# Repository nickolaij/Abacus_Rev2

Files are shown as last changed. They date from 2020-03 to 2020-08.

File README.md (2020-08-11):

# Abacus Mechanical Keyboard

A 45% mechanical keyboard that includes an encoder volume/scroll wheel and RGB lighting. 

This keyboard is powered by QMK, visit the [QMK Repository](https://github.com/qmk/qmk_firmware/) to see all the amazing keyboards supported by them.

AbacusBack
AbacusFront

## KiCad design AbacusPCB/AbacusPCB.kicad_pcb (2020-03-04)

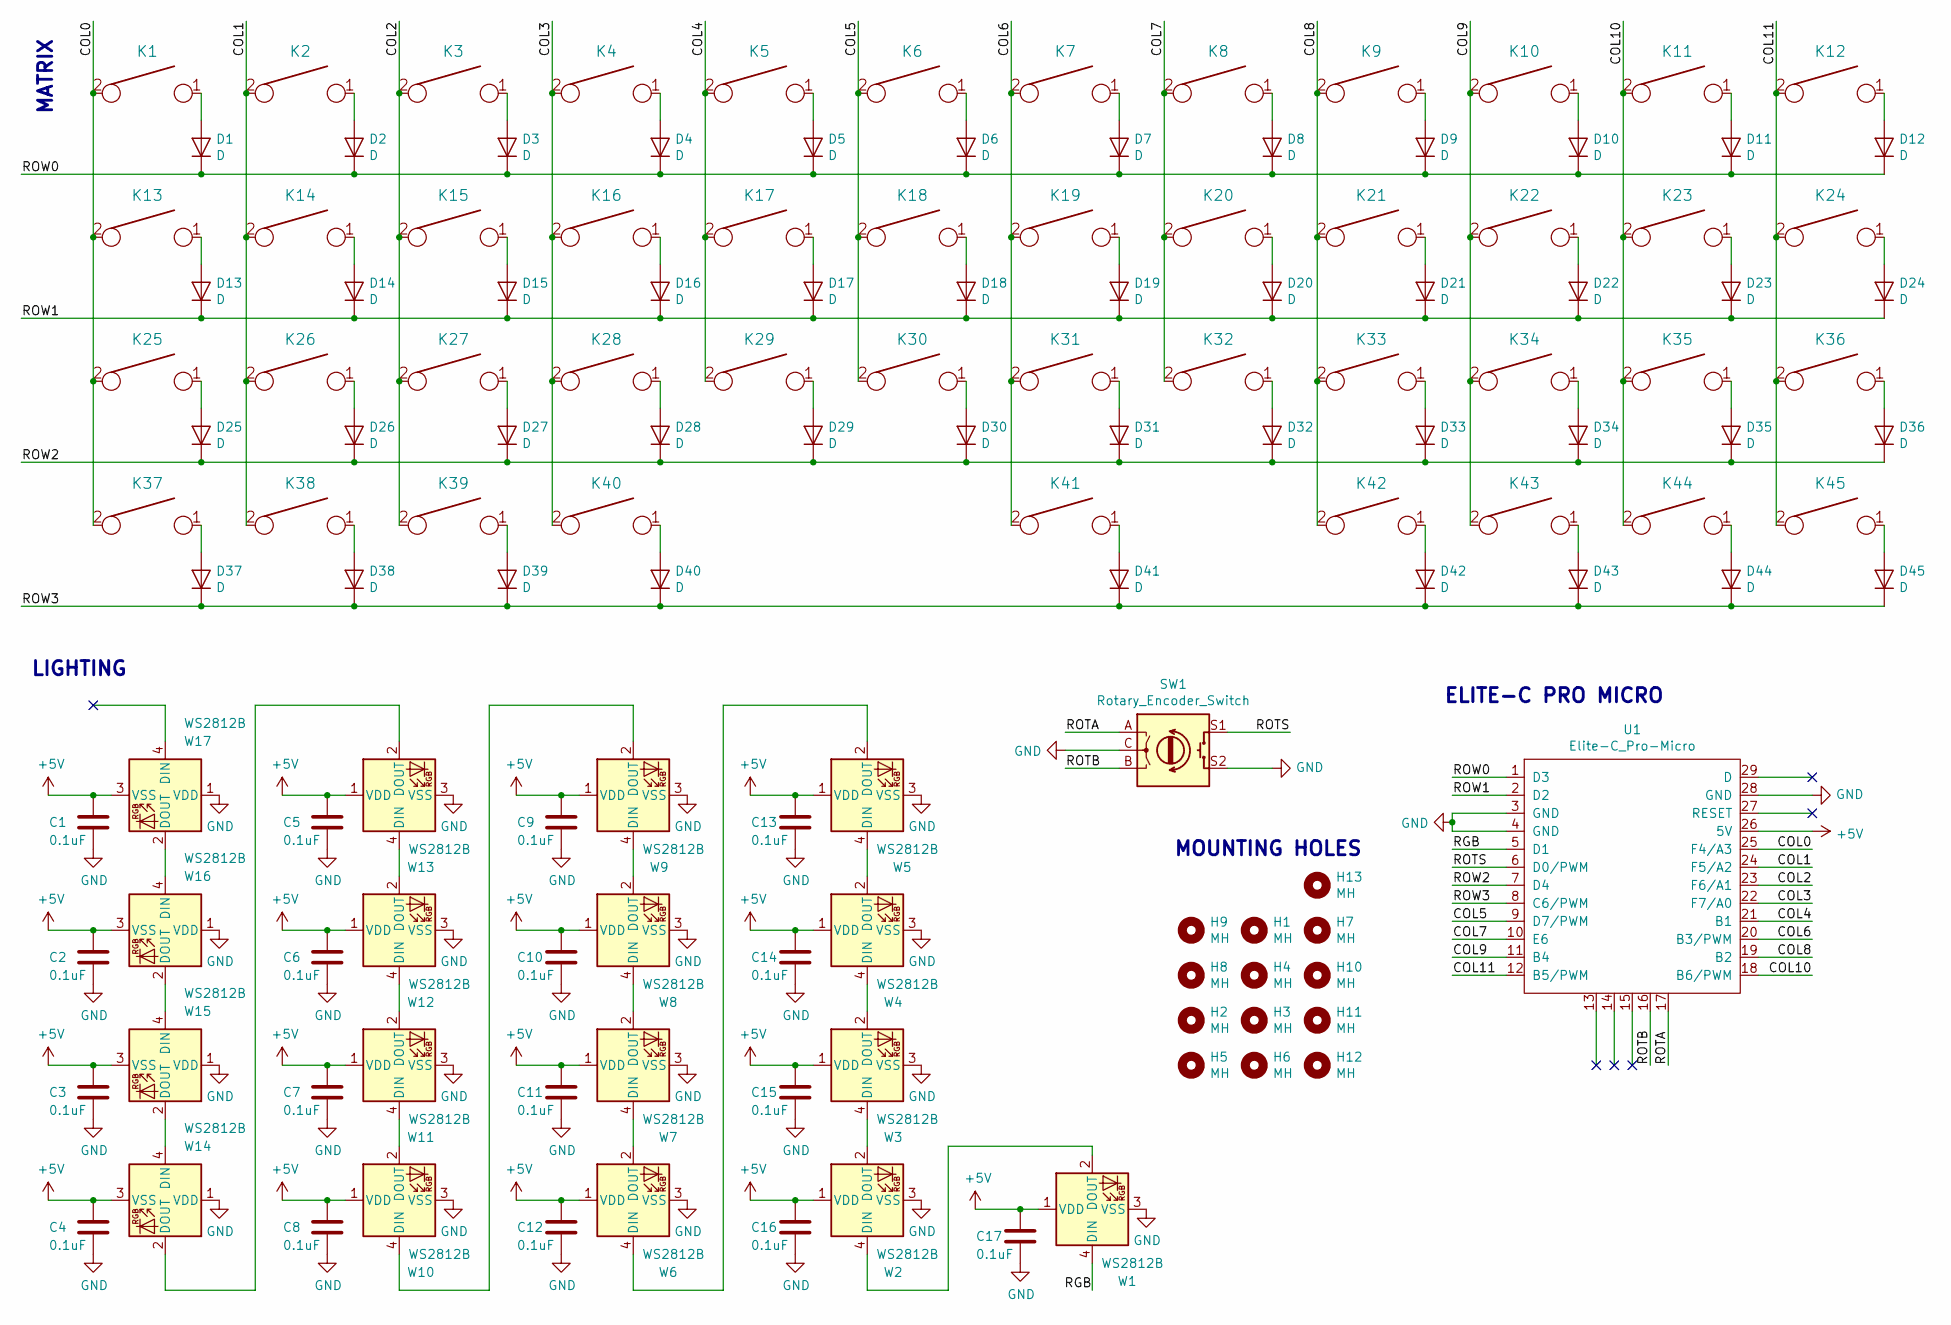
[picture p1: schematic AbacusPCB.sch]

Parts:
C1, C2, C3, C4, C5, C6, C7, C8, C9, C10, C11, C12, C13, C14, C15, C16, C17: 0.1uF; C_0603_1608Metric_Pad1.05x0.95mm_HandSolder
D1, D2, D3, D4, D5, D6, D7, D8, D9, D10, D11, D12, D13, D14, D15, D16, D17, D18, D19, D20, D21, D22, D23, D24, D25, D26, D27, D28, D29, D30, D31, D32, D33, D34, D35, D36, D37, D38, D39, D40, D41, D42, D43, D44, D45: D; Diode
H1, H2, H3, H4, H5, H6, H7, H8, H9, H10, H11, H12, H13: MH; M3 Hole
K1, K2, K3, K4, K5, K6, K7, K8, K9, K10, K11, K14, K15, K16, K17, K18, K19, K20, K21, K22, K23, K26, K27, K28, K29, K30, K31, K32, K33, K34, K35, K36, K38, K39, K42, K43, K44, K45: KEYSW; MX-1U-NoLED
K12, K25: KEYSW; MX-1.75U-NoLED
K13, K37: KEYSW; MX-1.25U-NoLED
K24: KEYSW; MX-1.5U-NoLED
K40, K41: KEYSW; MX-2.75U-ReversedStabilizers-NoLED
SW1: Rotary_Encoder_Switch; Encoder
U1: Elite-C_Pro-Micro; Elite-C Pro-Micro
W1, W2, W3, W4, W5, W6, W7, W8, W9, W10, W11, W12, W13, W14, W15, W16, W17: WS2812B; WS2812_Hand_Solder

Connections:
+5V: C1.1, C2.1, C3.1, C4.1, C5.1, C6.1, C7.1, C8.1, C9.1, C10.1, C11.1, C12.1, C13.1, C14.1, C15.1, C16.1, C17.1, U1.26 (5V), W1.1 (VDD), W2.1 (VDD), W3.1 (VDD), W4.1 (VDD), W5.1 (VDD), W6.1 (VDD), W7.1 (VDD), W8.1 (VDD), W9.1 (VDD), W10.1 (VDD), W11.1 (VDD), W12.1 (VDD), W13.1 (VDD), W14.3 (VSS), W15.3 (VSS), W16.3 (VSS), W17.3 (VSS)
/COL0: K1.2, K13.2, K25.2, K37.2, U1.25 (F4/A3)
/COL1: K2.2, K14.2, K26.2, K38.2, U1.24 (F5/A2)
/COL2: K3.2, K15.2, K27.2, K39.2, U1.23 (F6/A1)
/COL3: K4.2, K16.2, K28.2, K40.2, U1.22 (F7/A0)
/COL4: K5.2, K17.2, K29.2, U1.21 (B1)
/COL5: K6.2, K18.2, K30.2, U1.9 (D7/PWM)
/COL6: K7.2, K19.2, K31.2, K41.2, U1.20 (B3/PWM)
/COL7: K8.2, K20.2, K32.2, U1.10 (E6)
/COL8: K9.2, K21.2, K33.2, K42.2, U1.19 (B2)
/COL9: K10.2, K22.2, K34.2, K43.2, U1.11 (B4)
/COL10: K11.2, K23.2, K35.2, K44.2, U1.18 (B6/PWM)
/COL11: K12.2, K24.2, K36.2, K45.2, U1.12 (B5/PWM)
/RGB: U1.5 (D1), W1.4 (DIN)
/ROTA: SW1.A, U1.17
/ROTB: SW1.B, U1.16
/ROTS: SW1.S1, U1.6 (D0/PWM)
/ROW0: D1.1 (K), D2.1 (K), D3.1 (K), D4.1 (K), D5.1 (K), D6.1 (K), D7.1 (K), D8.1 (K), D9.1 (K), D10.1 (K), D11.1 (K), D12.1 (K), U1.1 (D3)
/ROW1: D13.1 (K), D14.1 (K), D15.1 (K), D16.1 (K), D17.1 (K), D18.1 (K), D19.1 (K), D20.1 (K), D21.1 (K), D22.1 (K), D23.1 (K), D24.1 (K), U1.2 (D2)
/ROW2: D25.1 (K), D26.1 (K), D27.1 (K), D28.1 (K), D29.1 (K), D30.1 (K), D31.1 (K), D32.1 (K), D33.1 (K), D34.1 (K), D35.1 (K), D36.1 (K), U1.7 (D4)
/ROW3: D37.1 (K), D38.1 (K), D39.1 (K), D40.1 (K), D41.1 (K), D42.1 (K), D43.1 (K), D44.1 (K), D45.1 (K), U1.8 (C6/PWM)
GND: C1.2, C2.2, C3.2, C4.2, C5.2, C6.2, C7.2, C8.2, C9.2, C10.2, C11.2, C12.2, C13.2, C14.2, C15.2, C16.2, C17.2, SW1.C, SW1.S2, U1.3 (GND), U1.4 (GND), U1.28 (GND), W1.3 (VSS), W2.3 (VSS), W3.3 (VSS), W4.3 (VSS), W5.3 (VSS), W6.3 (VSS), W7.3 (VSS), W8.3 (VSS), W9.3 (VSS), W10.3 (VSS), W11.3 (VSS), W12.3 (VSS), W13.3 (VSS), W14.1 (VDD), W15.1 (VDD), W16.1 (VDD), W17.1 (VDD)
unnamed: D1.2 (A), K1.1
unnamed: D2.2 (A), K2.1
unnamed: D3.2 (A), K3.1
unnamed: D4.2 (A), K4.1
unnamed: D5.2 (A), K5.1
unnamed: D6.2 (A), K6.1
unnamed: D7.2 (A), K7.1
unnamed: D8.2 (A), K8.1
unnamed: D9.2 (A), K9.1
unnamed: D10.2 (A), K10.1
unnamed: D11.2 (A), K11.1
unnamed: D12.2 (A), K12.1
unnamed: D13.2 (A), K13.1
unnamed: D14.2 (A), K14.1
unnamed: D15.2 (A), K15.1
unnamed: D16.2 (A), K16.1
unnamed: D17.2 (A), K17.1
unnamed: D18.2 (A), K18.1
unnamed: D19.2 (A), K19.1
unnamed: D20.2 (A), K20.1
unnamed: D21.2 (A), K21.1
unnamed: D22.2 (A), K22.1
unnamed: D23.2 (A), K23.1
unnamed: D24.2 (A), K24.1
unnamed: D25.2 (A), K25.1
unnamed: D26.2 (A), K26.1
unnamed: D27.2 (A), K27.1
unnamed: D28.2 (A), K28.1
unnamed: D29.2 (A), K29.1
unnamed: D30.2 (A), K30.1
unnamed: D31.2 (A), K31.1
unnamed: D32.2 (A), K32.1
unnamed: D33.2 (A), K33.1
unnamed: D34.2 (A), K34.1
unnamed: D35.2 (A), K35.1
unnamed: D36.2 (A), K36.1
unnamed: D37.2 (A), K37.1
unnamed: D38.2 (A), K38.1
unnamed: D39.2 (A), K39.1
unnamed: D40.2 (A), K40.1
unnamed: D41.2 (A), K41.1
unnamed: D42.2 (A), K42.1
unnamed: D43.2 (A), K43.1
unnamed: D44.2 (A), K44.1
unnamed: D45.2 (A), K45.1
unnamed: W1.2 (DOUT), W2.4 (DIN)
unnamed: W2.2 (DOUT), W3.4 (DIN)
unnamed: W3.2 (DOUT), W4.4 (DIN)
unnamed: W4.2 (DOUT), W5.4 (DIN)
unnamed: W5.2 (DOUT), W6.4 (DIN)
unnamed: W6.2 (DOUT), W7.4 (DIN)
unnamed: W7.2 (DOUT), W8.4 (DIN)
unnamed: W8.2 (DOUT), W9.4 (DIN)
unnamed: W10.2 (DOUT), W11.4 (DIN)
unnamed: W9.2 (DOUT), W10.4 (DIN)
unnamed: W11.2 (DOUT), W12.4 (DIN)
unnamed: W12.2 (DOUT), W13.4 (DIN)
unnamed: W13.2 (DOUT), W14.2 (DOUT)
unnamed: W14.4 (DIN), W15.2 (DOUT)
unnamed: W15.4 (DIN), W16.2 (DOUT)
unnamed: W16.4 (DIN), W17.2 (DOUT)

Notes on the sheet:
MATRIX
MOUNTING HOLES
LIGHTING
ELITE-C PRO MICRO

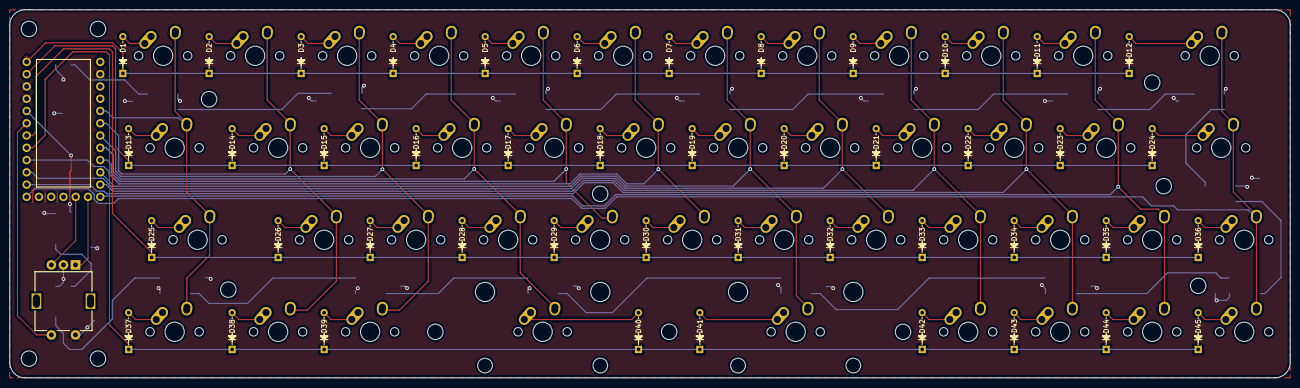
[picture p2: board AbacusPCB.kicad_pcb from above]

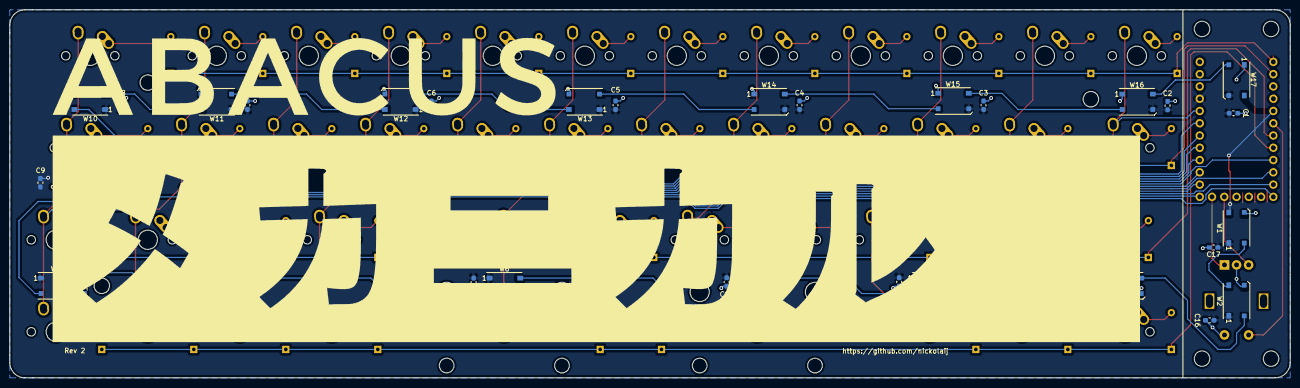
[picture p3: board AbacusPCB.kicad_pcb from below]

Board: 2 copper layers, 265.1 x 76.2 mm, 139 parts (35 on the bottom side), 83 nets.

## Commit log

2020-02-09 gerbers sent
    [AbacusPCB.kicad_pcb, AbacusPCB.sch]
2020-02-09 celebatory push
    [AbacusPCB-B_Cu.gbr, AbacusPCB-B_Mask.gbr, AbacusPCB-B_SilkS.gbr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]
2020-03-04 finalisation changes for public release
    [AbacusPCB.kicad_pcb, AbacusPCB.sch]
